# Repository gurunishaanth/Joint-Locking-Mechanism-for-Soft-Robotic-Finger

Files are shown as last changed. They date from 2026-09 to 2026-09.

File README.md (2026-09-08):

# Soft-Robotic-Finger
This is the final backup of my thesis project. <br>
I have some SolidWorks files and some PDFs from the initial process. <br>
Guru Nishaanth Saravanan_MA.pdf is my final Thesis
# Legend
So, <br>
RP means Rack and pinion mechanism. <br>
CM means Compliant mechanism. <br>
LA means linear actuator mechanism. <br>
EM means Electromagnetic mechanism. <br>

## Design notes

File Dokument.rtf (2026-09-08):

Documentation For The Thesis
Week 1(1/9 - 5/9)
Prep for the literature review
Week 2(8/9 - 12/9)
First version of compliant mech
Week 3(15/9 - 19/9)
Thesis write-up and the next version of comp
Documentation
Week 4(22/9 - 26/9)
First version of finger
Documentation
Week 5(29/9 - 3/10)
First version of finger mold
Second version of finger and mold
Documentation
Week 6(6/10 - 10/10)
next version of finger and mold
Documentation
Week 7 (13/10 - 17/10)
First version of Hand design
Documentation
Week 8 (20/10 - 25/10)
Redesign of the finger tip(finger nail)
List of the actuators
Documentation
Week 9 (27/10 - 31/10)
initial mold arrived
Redesign of the whole finger(high width)
design the flex test
Documentation
Week 10(3/11 - 7/11)
design the new mechanism with a rack and pinion
Search for materials
measuring the linear actuator
design the new mechanism with a linear actuator
Documentation
Week 11 (10/11 - 14/11)
Redesign finger
Redesign the RP mechanism and LA mechanism
Documentation
Week 12 (17/11 - 21/11)
Initial print for the comp mech and TPU finger acquired after the 3d print
Documentation
initial re-design drawing and list prep for the re-design
Week 13 (23/11 - 28/11)
Redesign of LA
Redesign of RP
Redesign of finger and molds
Finger design with single string
Week 14(1/12 - 5/12)
Electromagnet 4 parts and lid done
Motor lock structure
test joint v3 and v4 and molds
First test joint done here
Week 15 (8/12 - 12/12)
fabrication part
second attempt on the same test joint
redesign some parts
palm v2
Week 16 (15/12 - 19/12)
Break
Week 17 (22/9 - 26/9)
Break
Week 18 (29/12 - 2/1)
Break
Week 19 (7/1 - 9/1)
Break
Week 20 (12/1 - 16/1)
Break
Week 21 (19/1 - 24/1)
Summary of the project
small re-designs
parameters to choose the actuators acquired
literature review structure
Week 22 (26/1 - 31/1)
Trying to make the electromagnet work
works but very low power, ordered the power supply
Trying to make the linear actuator work
NOT WORKING

Week 23 (2/2 - 7/2)
Trying to make the linear actuator work
NOT WORKING
searching for a new driver.
EM parts redesign
Vachum chamber arrived.
Base test is working.
Did a mold test, added less silicone, so failed.

Week 24 (10/2 - 13/2)
Did a full finger Mold test - WITH VACUME CHAMBER
working but there are bubbles on the top.
EM parts new re-design
nail re-design - (too tight; HARD FOR THE THREAD TO GO IN.)
mold top part redesign

Week 25 (16/2 - 20/2)
full mold design start(discussion)
soft robotic arm redesign
Documentation

Week 26 (22/2 - 27/2)
Single finger BASE
Got the 3d printed parts
Assembled new LA case
new finger got from mold

Week 27 (2/3 - 6/3)
Power source, LA Driver, and Jumper wires arrived
Single-finger base assembled
new finger added the string
EM test code completed
EM basic test - 12V attracts properly

Week 28 (9/3 - 13/3)
LA Test code completed
LA basic test - 6V moves properly, but the 90 Â° movement doesn't work
LA Redesign was done
LA full finger model started

Week 29 (16/3 - 20/3)
LA full finger model the bend thing
LA full finger model molds
EM full finger model the bend thing
EM full finger model molds started
got some 3D printed parts

Week 30 (22/3 - 27/3)
Got 2 souldered LA
broke one Got 1 RP motor
broke Got some 3D printed parts
mini test RP RP redesign
Week 31 (30/3 - 3/4)
EM mold re-design
LA re-design
3D print parts
RP test code

Week 32 (6/4 - 10/4)
got H-bridge, silicon glue, silicone
LA full finger casted

Week 33 (13/4 - 17/4)
worked on LA control
writing
recived 3d prints

Week 34 (20/4 - 24/4)
writing
Control done
Redesign the finger base

Week 35 (27/4 - 1/5)
Literature review writing
Redesign the backbone from plastic to leaf spring
Experimental design writing

Week 36 (4/5 - 8/5)
Experimental design writing
leaf spring initial experiments

Week 37 (18/5 - 22/5)
power experiment set up done
LA finger plastic

Week 38 (25/5 - 29/5)

Week 39 (2/6 - 6/6)

Week 40 (8/6 - 12/6)

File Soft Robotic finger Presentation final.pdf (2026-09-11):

1 | Joint locking mechanisms for Soft Robotic Finger | Guru Nishaanth Saravanan

# Joint Locking Mechanisms for Soft Robotic Finger

# Master’s Thesis

### From Guru Nishaanth Saravanan

1st supervisor: Dr.Julia Starke | 2nd supervisor: Dr. Georg Schildbach

2 | Joint locking mechanisms for Soft Robotic Finger | Guru Nishaanth Saravanan

## Introduction

## Soft Robotics

- High compliance
- Safer robot-human interaction
- Adaptive grasping with fragile and irregular objects.
- Low precision and load capacity

## Hybrid - This Thesis

- Soft Body + locking mechanism
- High compliance
- Safer robot-human interaction
- Adaptive grasping with fragile and irregular objects.
- Higher precision
- Better load capacity

## Rigid Robotics

- High precision and load
capacity
- Poor compliance
- Challenge in interaction with fragile objects and
unstructured environment

[1]

1
2

[2]

3 | Joint locking mechanisms for Soft Robotic Finger | Guru Nishaanth Saravanan

## Introduction

## Need for Locking mechanisms

- Underactuated robotic had uses locking mechanisms to compensate the lack of
actuators.
- These mechanisms locks the fingers on certain positions to have more dexterity by having multiple configurations

## Underactuated Robotics

Drive multiple joints from a single actuator through passive tendon or linkage coupling.

1
2

[1]

4 | Joint locking mechanisms for Soft Robotic Finger | Guru Nishaanth Saravanan

## Literature Review

UT Hand 1 | Mag-Net finger
- This hand is a rigid, underactuated hand that uses a motor to control each finger’s flexion.
- It has an embedded solenoid-based pin-locking mechanism and is used to stop the joint rotation; therefore, locking the joint is in a single position.
- This soft finger is cast using the silicone casting method and is capable of performing flexion motion.
- It has embedded
electromagnetic coils

The gap
Locking strategies exist for rigid systems, but the integration of an embedded rigid locking element into a soft system is non-existent.

[1]

[1]

[3]

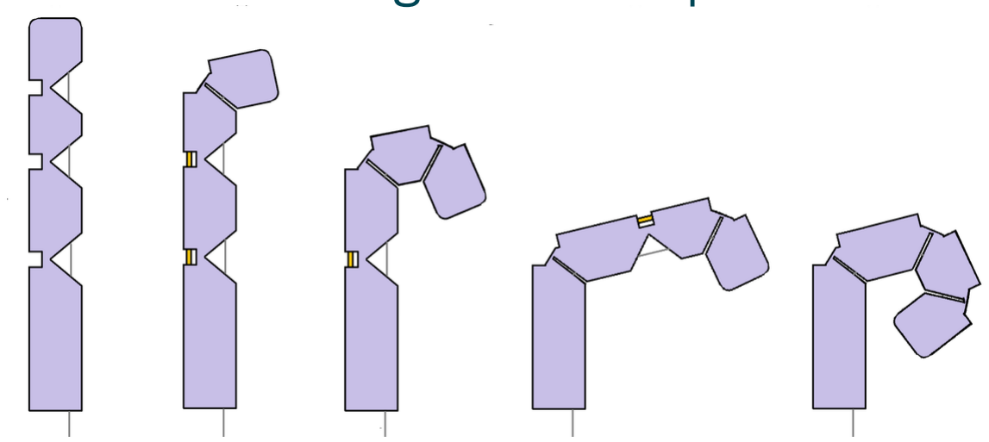
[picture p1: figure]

5 | Joint locking mechanisms for Soft Robotic Finger | Guru Nishaanth Saravanan

## Motivation and Research Gap

The main motivation of the thesis is to make a soft robotic finger that can achieve multiple configurations

How? | Thesis objective
| • Propose and compare multiple candidate mechanisms. • Select and integrate the locking mechanisms into a silicon-cast, tendon-driven finger. • Experiment and validate at mechanism- and finger-level

By implementing, a discrete, electrically controlled locking mechanism, embedded in a soft finger to hold multiple grasp configurations without sacrificing softness or adding excessive power draw.

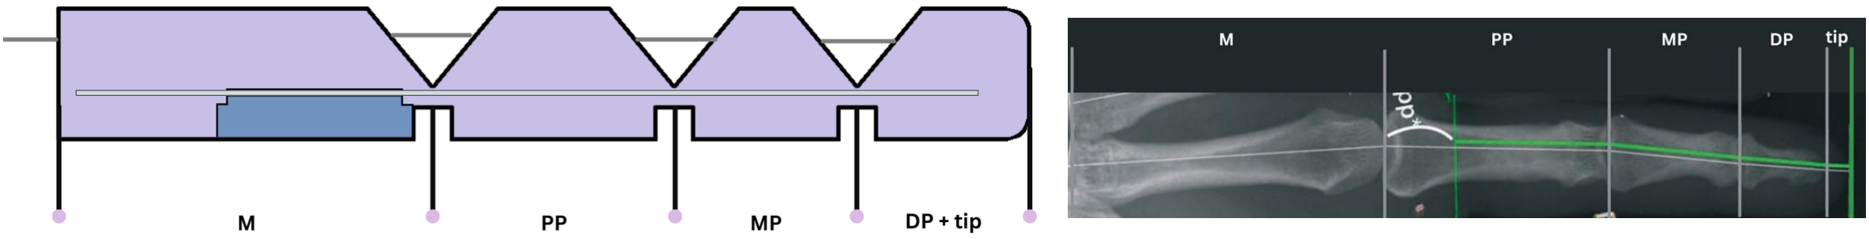
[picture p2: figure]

6 | Joint locking mechanisms for Soft Robotic Finger | Guru Nishaanth Saravanan

## Finger Design

90°
Angle of the finger joint

≥250°
Total Range of motion

(Key requirements)

Segment lengths are constrained to within the anatomically derived targets, keeping proportions consistent with the human middle finger.

Joint 1 | Joint 2 | Joint 3

[4]

## Locking mechanism selection

7 | Joint locking mechanisms for Soft Robotic Finger | Guru Nishaanth Saravanan
Screw based linear mechanism | Rack and pinion mechanism | Compliant mechanism
Electromagnetic mechanism | Pulley system

## Locking mechanism selection

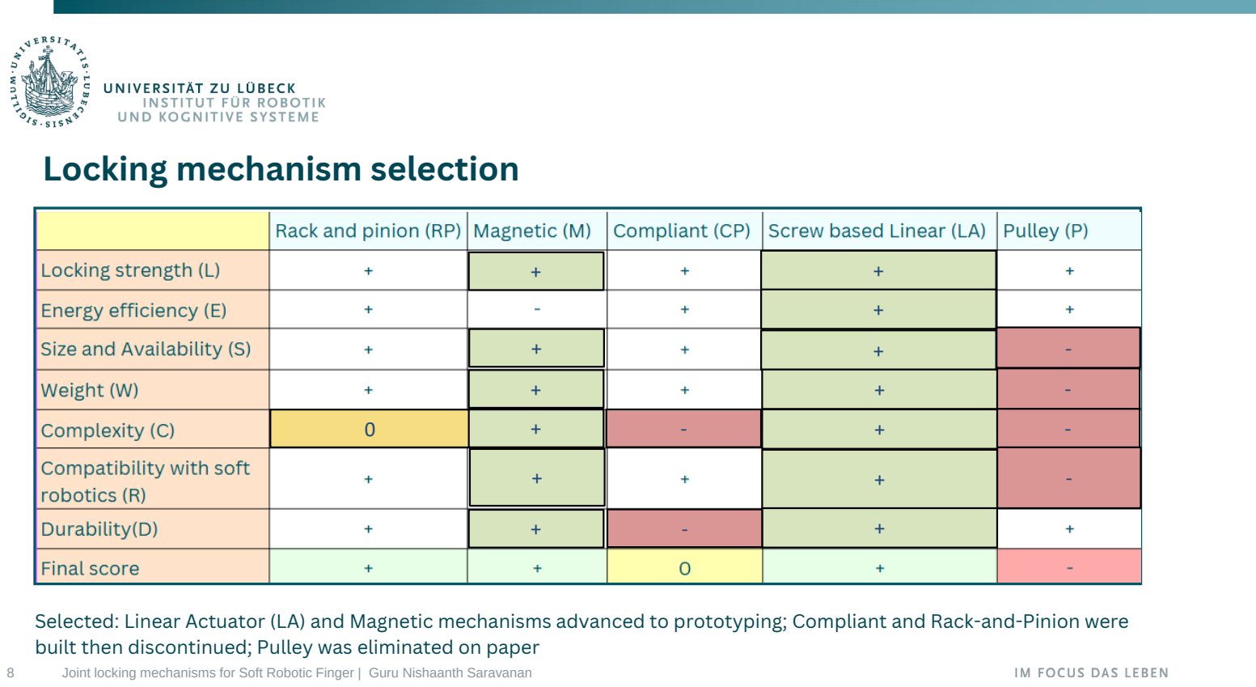
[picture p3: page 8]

8 | Joint locking mechanisms for Soft Robotic Finger | Guru Nishaanth Saravanan

Selected: Linear Actuator (LA) and Magnetic mechanisms advanced to prototyping; Compliant and Rack-and-Pinion were built then discontinued; Pulley was eliminated on paper

0 | + | - | + | -
| + | | + | -

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
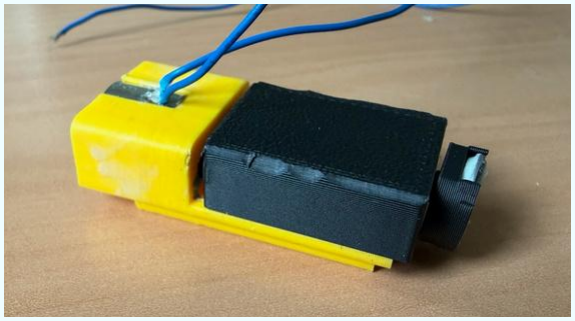
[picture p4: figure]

9 | Joint locking mechanisms for Soft Robotic Finger | Guru Nishaanth Saravanan

## Mechanism designs

Electromagnet Mechanism | Linear actuator Mechanism
- This mechanism relies on an electromagnet and the metal piece for locking. • An electromagnet rated at 24 V, 1.0W, is used for this purpose. | • CA-1006 micro stepper motor - 9 mm stroke is used for this mechanism • Screw-based threaded shaft drives non- backdrivable linear lock.

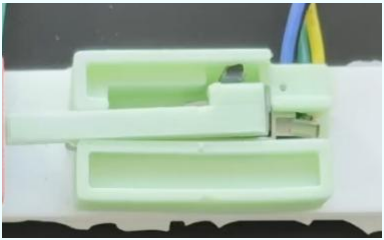
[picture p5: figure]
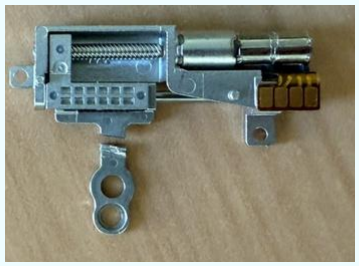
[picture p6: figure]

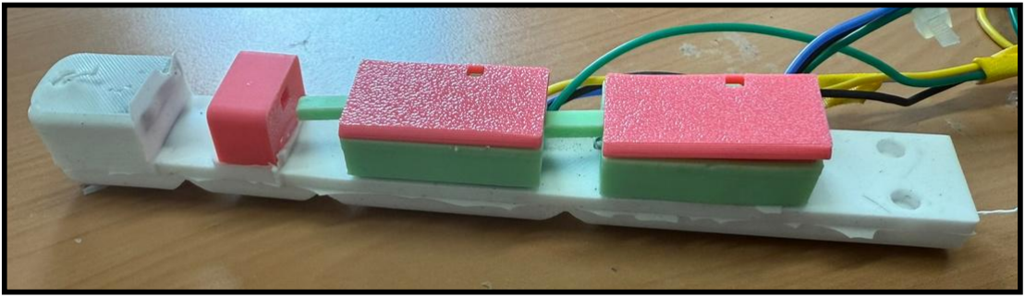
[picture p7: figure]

10 | Joint locking mechanisms for Soft Robotic Finger | Guru Nishaanth Saravanan

## Final fingers

- Two of these final fingers are tested to find the best mechanism, and the best candidate can be used for further construction.
- Locking currently implemented at Joints 1 and 2
- Tendon-driven actuation with PTFE-lined channels
- Anatomically-proportioned segments (166 mm total length)

With the electromagnet mechanisms

With the linear actuator mechanisms

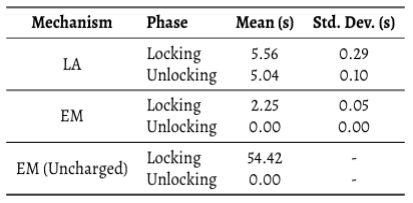
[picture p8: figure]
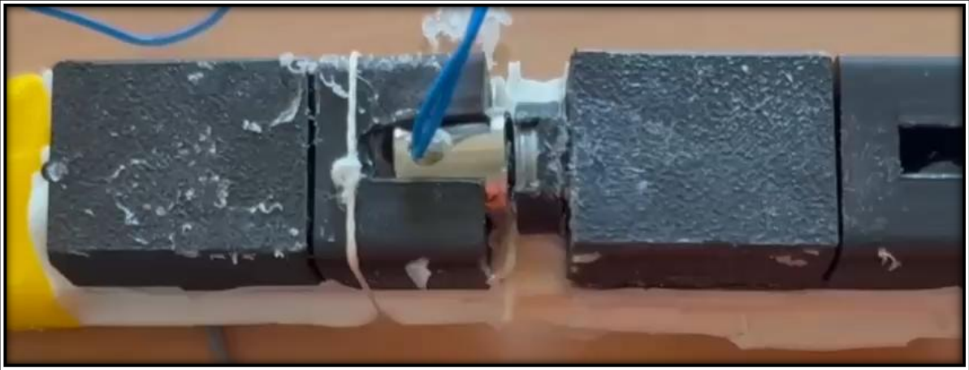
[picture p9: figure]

11 | Joint locking mechanisms for Soft Robotic Finger | Guru Nishaanth Saravanan

## Activation time

## 2.5 s

Electromagnet

## 5.5 s

Linear actuator

Avg Locking time

## Mechanism-Level Experiments

## Power consumption

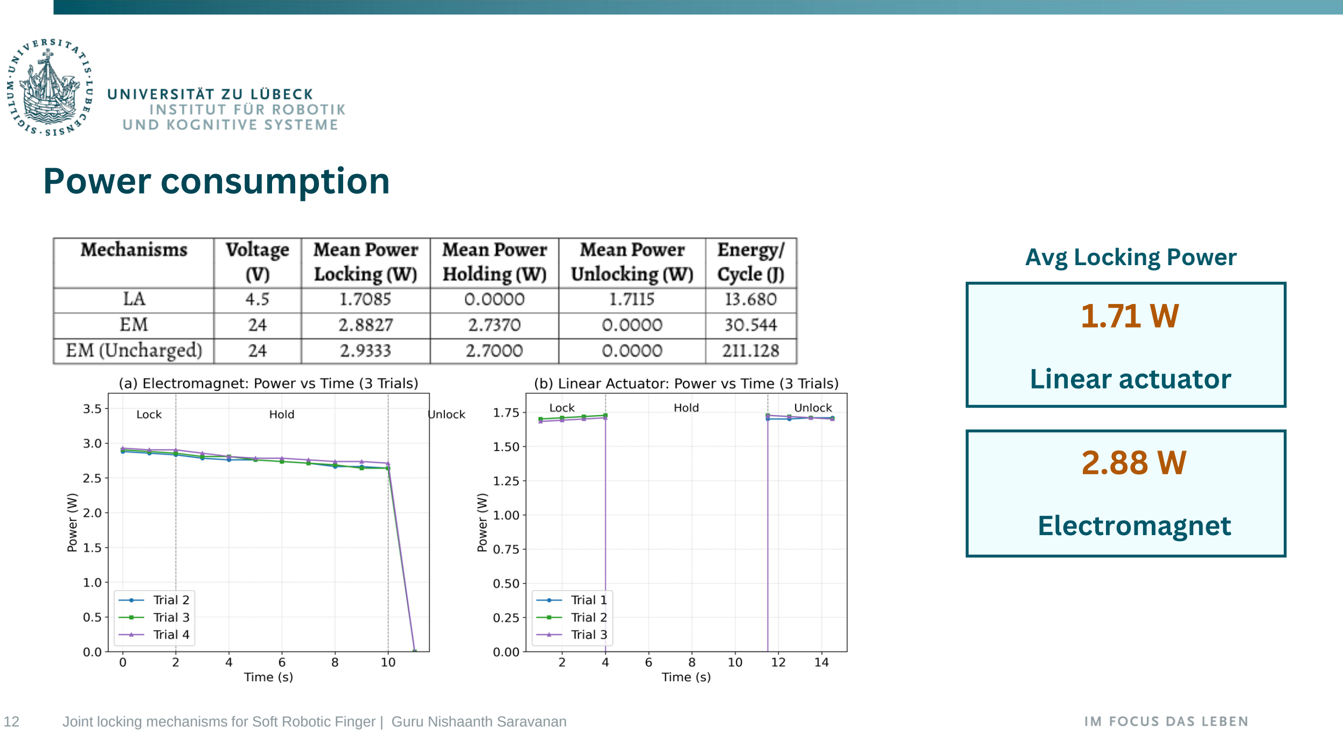
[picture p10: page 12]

12 | Joint locking mechanisms for Soft Robotic Finger | Guru Nishaanth Saravanan

## 2.88 W

Electromagnet

## 1.71 W

Linear actuator

Avg Locking Power

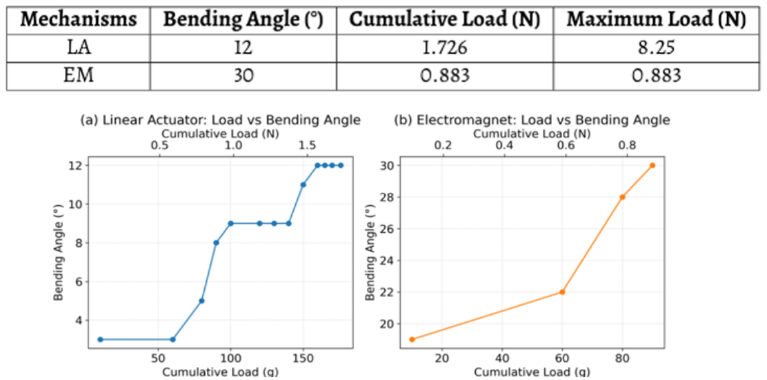
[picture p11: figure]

13 | Joint locking mechanisms for Soft Robotic Finger | Guru Nishaanth Saravanan

## Load carried

## 0.88 N

Electromagnet

## 8.25 N

Linear actuator

Maximum Load

14 | Joint locking mechanisms for Soft Robotic Finger | Guru Nishaanth Saravanan

## Mechanisms overview

### Criteria

Avg. locking time Avg. locking power Max. load Applied | 5.5 s 1.74W 8.25 N | 2.5 s 2.88 W 0.88 N | Electromagnet Linear actuator Linear actuator
| | Final Choice | Linear actuator

### Linear actuator

### Electromagnet

### Preferred

15 | Joint locking mechanisms for Soft Robotic Finger | Guru Nishaanth Saravanan
Tendon pull force | Finger tip strength

2.78 ± 0.24N

Total pull force required

4.1 ± 0.5 N

Finger tip grip strength

- To measure the grip strength of the finger, quantified as the force exerted by the fingertip when fully actuated.
- Key indicator of the finger’s ability to grasp and hold objects during practical use.
- To determine the force required to pull the tendon of the finger through its full range of motion.
- This force is used to calculate the torque required for the actuating motor.

## Finger-Level Experiments

## Precision and repeatability

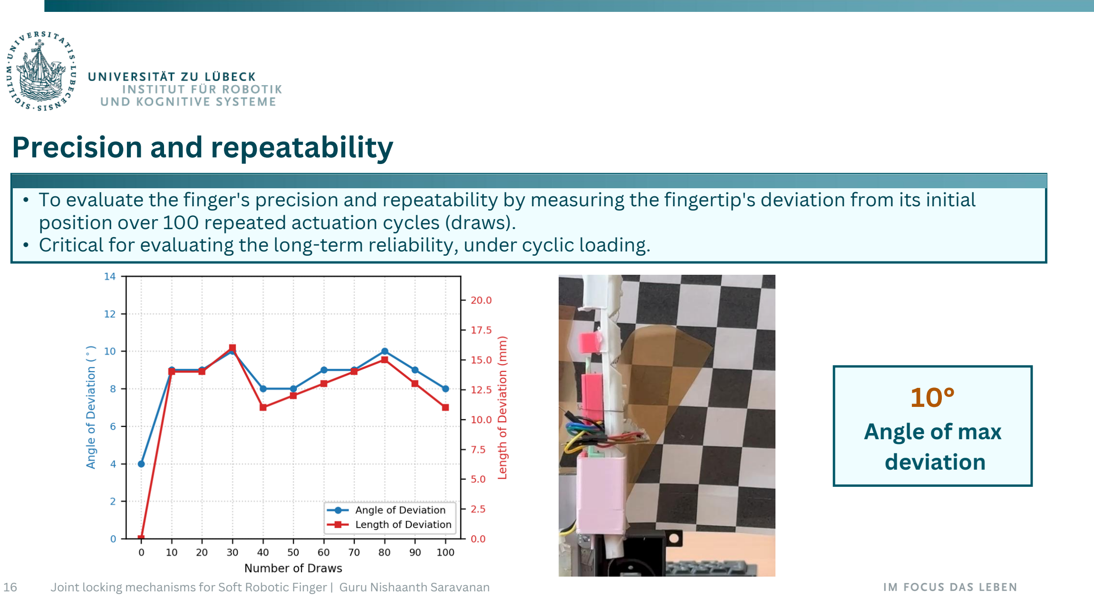
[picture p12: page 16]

16 Joint locking mechanisms for Soft Robotic Finger | Guru Nishaanth Saravanan
- To evaluate the finger's precision and repeatability by measuring the fingertip's deviation from its initial position over 100 repeated actuation cycles (draws).
- Critical for evaluating the long-term reliability, under cyclic loading.

10°
Angle of max
deviation

## Range of motion

17 | Joint locking mechanisms for Soft Robotic Finger | Guru Nishaanth Saravanan
Joint 1 Locked | Joint 2 Locked | Joint 1 and 2 Locked | No Joint Locked

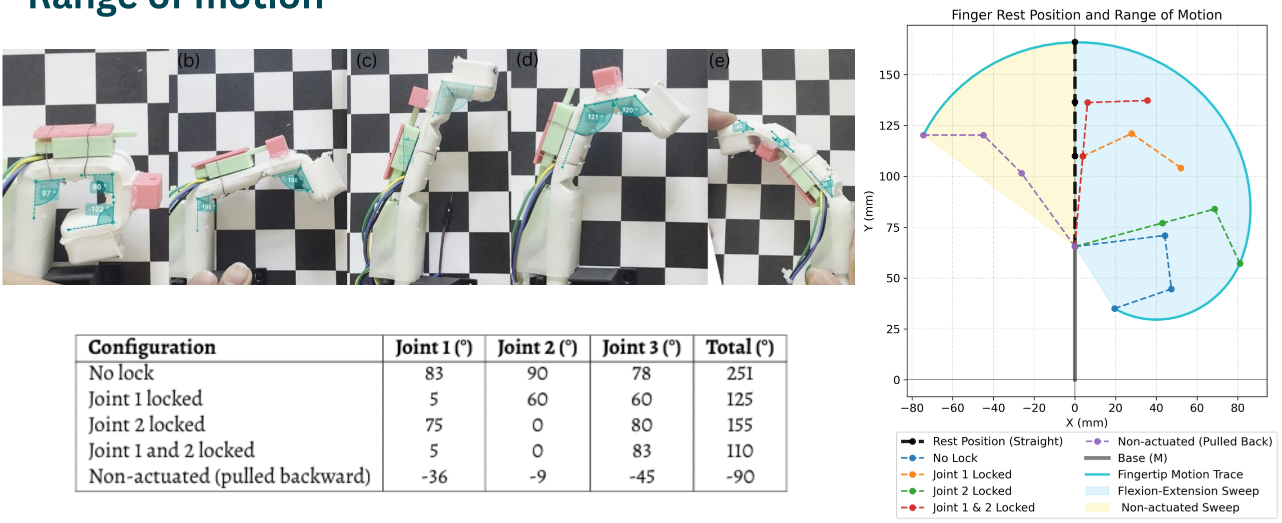
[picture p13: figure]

18 | Joint locking mechanisms for Soft Robotic Finger | Guru Nishaanth Saravanan

## Range of motion

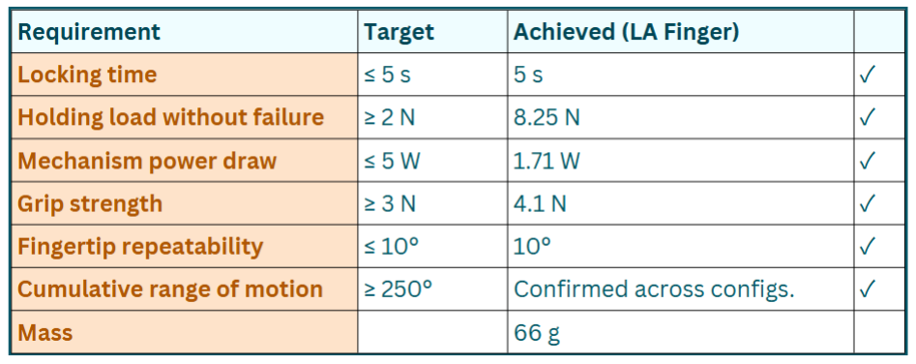
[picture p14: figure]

19 | Joint locking mechanisms for Soft Robotic Finger | Guru Nishaanth Saravanan

## Overview

The target values are taken from the chapter 3 of the thesis.

20 | Joint locking mechanisms for Soft Robotic Finger | Guru Nishaanth Saravanan

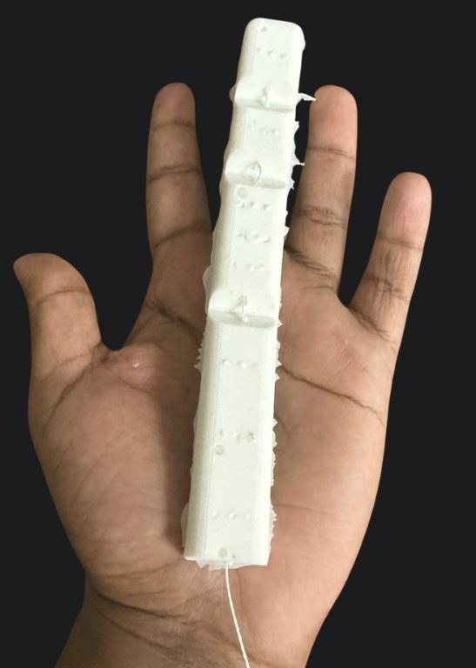
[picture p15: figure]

- Soft finger with an embedded locking mechanism was designed, fabricated, and validated.
- Candidate mechanisms were compared then the linear actuator and electromagnet were carried through to the final designs.
- These two mechanisms were put through an experimental analysis, where the linear actuator was chosen as the final candidate mechanism.
- Experimental results confirm posture retention under load without compromising its inherent soft properties.

## Conclusion

21 | Joint locking mechanisms for Soft Robotic Finger | Guru Nishaanth Saravanan

## Future works

### Motor actuation

Use measured tendon-pull-force data to calculate the required motor torque for optimal actuator selection.

### Full Hand

Scale from a single finger to five fingers integrated into a complete soft robotic hand.

22 | Joint locking mechanisms for Soft Robotic Finger | Guru Nishaanth Saravanan

# Thank you for your attention

Any
questions?

22 | Joint locking mechanisms for Soft Robotic Finger | Guru Nishaanth Saravanan

# References

1. Peerdeman,B et al., UT hand I:A lock-based underactuated hand prosthesis. In: Mechanism and Machine Theory.
2. Pagoli,A et al., A Soft Robotic Gripper With an Active Palm and Reconfigurable Fingers for Fully Dexterous In-Hand Manipulation. In: IEEE Robotics and Automation Letters.
3. Bolanakis,G.and Papadopoulos,E. Introducing Mag-Nets: Rapidly Bending Electromagnetic Actuators for Self-Contained Soft Robots. In: IEEE Robotics and Automation Letters.
4. Buryanov,A and Kotiuk,V. Proportions of Hand Segments. In: International Journal of Morphology.

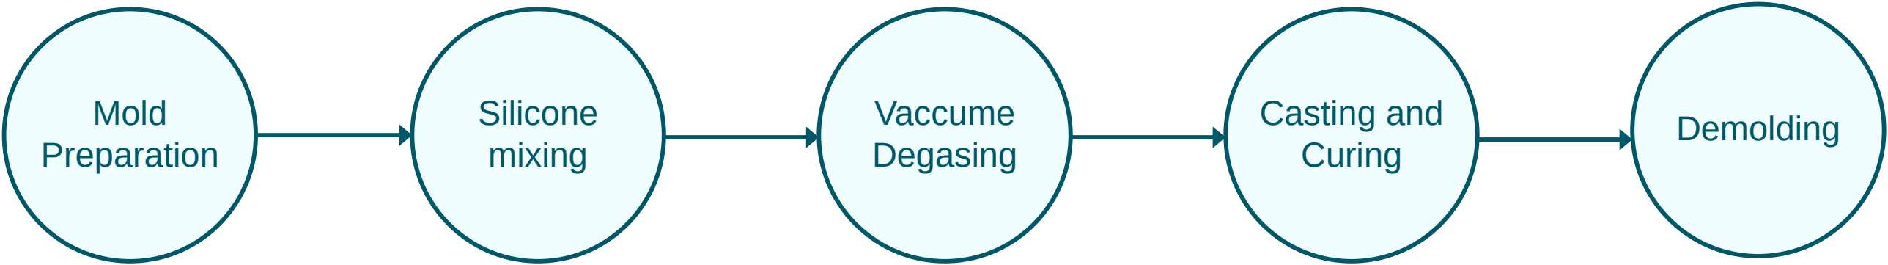
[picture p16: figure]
Mold Preparation; Silicone mixing; Vaccume Degasing; Casting and Curing; Demolding

24 | Joint locking mechanisms for Soft Robotic Finger | Guru Nishaanth Saravanan

## Finger fabrication

25 | Joint locking mechanisms for Soft Robotic Finger | Guru Nishaanth Saravanan

## Compliant mechanism

## Rack and pinion mechanism

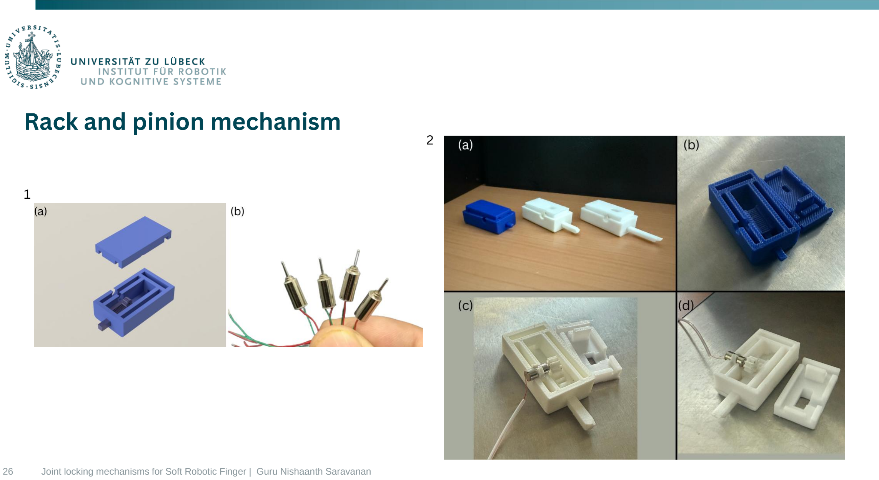
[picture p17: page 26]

26 | Joint locking mechanisms for Soft Robotic Finger | Guru Nishaanth Saravanan

1

2

## Electromagnet mechanism

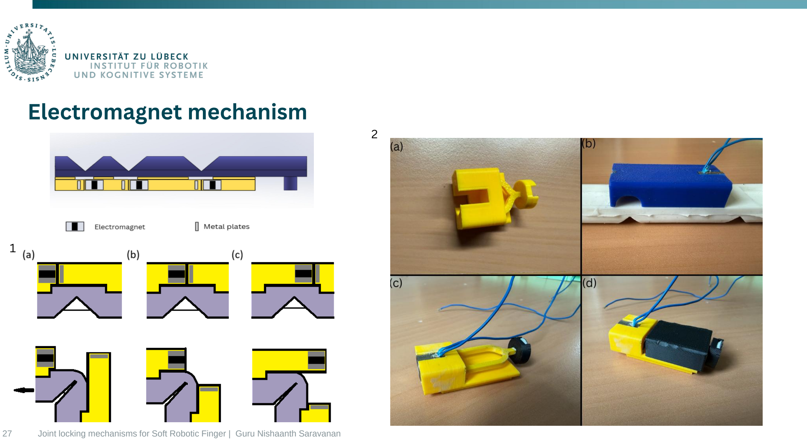
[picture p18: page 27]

27 | Joint locking mechanisms for Soft Robotic Finger | Guru Nishaanth Saravanan

1

2

## Linear actuator mechanism

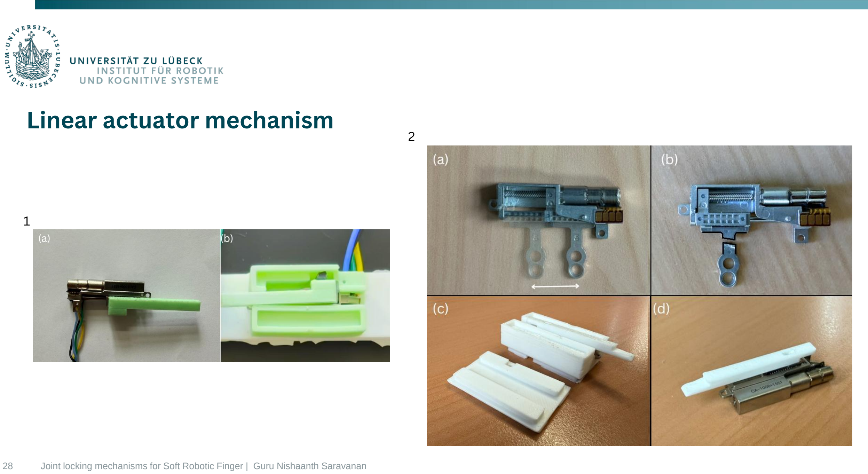
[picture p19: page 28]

28 | Joint locking mechanisms for Soft Robotic Finger | Guru Nishaanth Saravanan

2

1

29 | Joint locking mechanisms for Soft Robotic Finger | Guru Nishaanth Saravanan

## Spring Steel and PLA backbone

Flexion motion | Modular finger

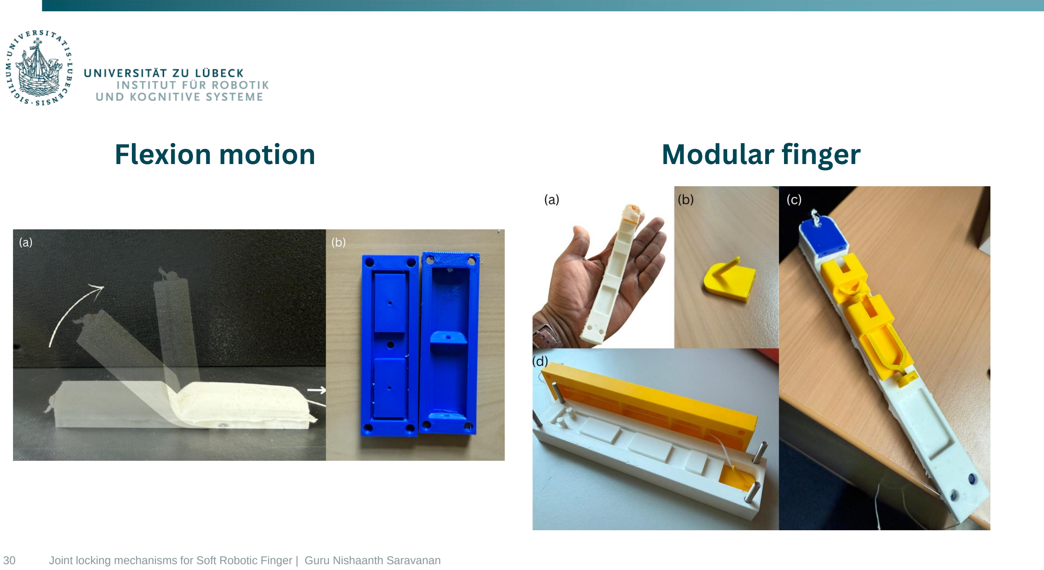
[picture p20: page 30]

30 | Joint locking mechanisms for Soft Robotic Finger | Guru Nishaanth Saravanan

LA finger | EM finger

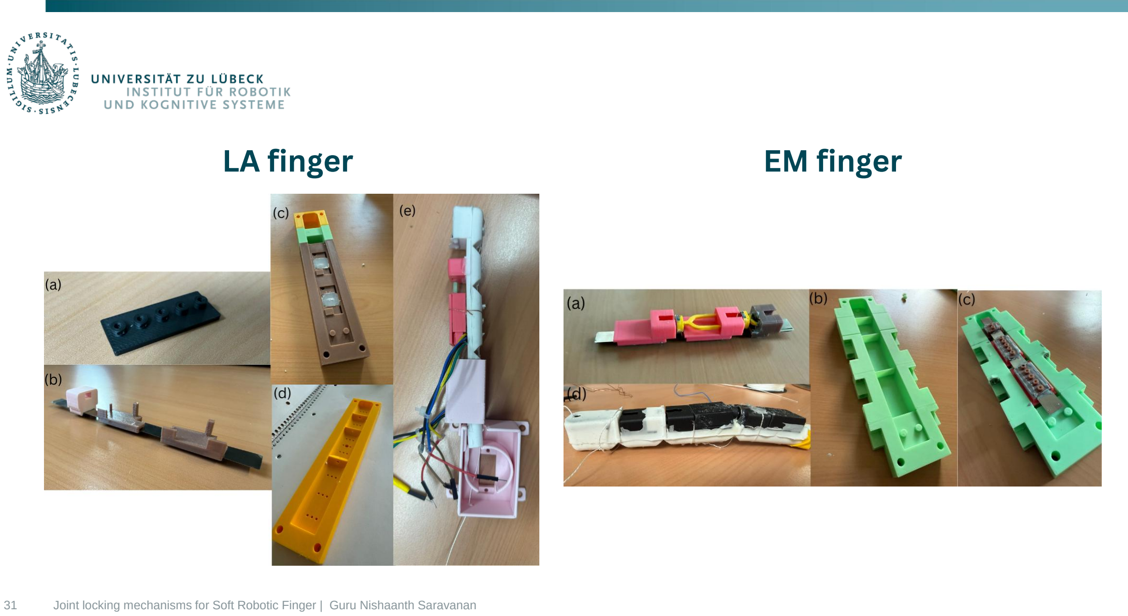
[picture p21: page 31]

31 | Joint locking mechanisms for Soft Robotic Finger | Guru Nishaanth Saravanan

## Experiments

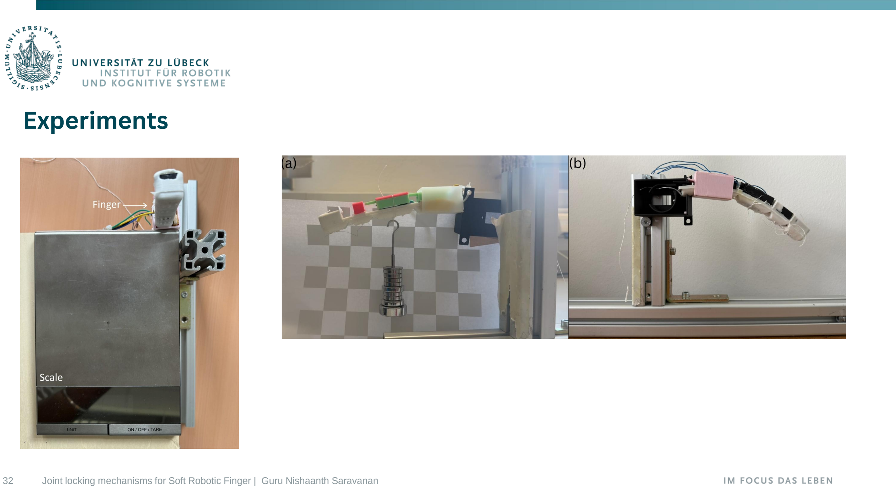
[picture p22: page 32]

32 | Joint locking mechanisms for Soft Robotic Finger | Guru Nishaanth Saravanan

## Control

33 | Joint locking mechanisms for Soft Robotic Finger | Guru Nishaanth Saravanan

## Versions

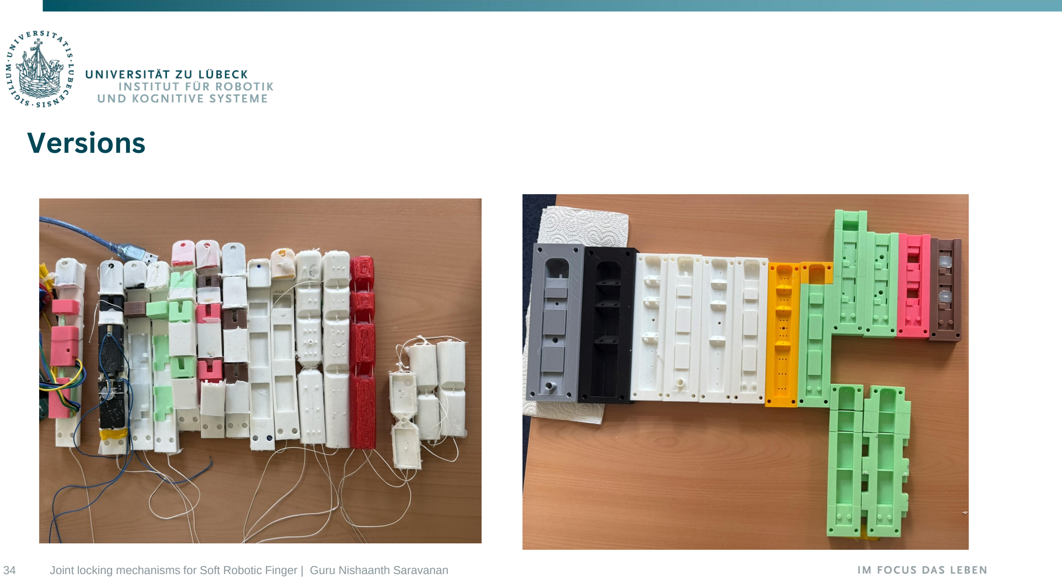
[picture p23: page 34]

34 | Joint locking mechanisms for Soft Robotic Finger | Guru Nishaanth Saravanan

35 | Joint locking mechanisms for Soft Robotic Finger | Guru Nishaanth Saravanan

## Driving Actuator vs the locking actuator

- Smaller
- less power consuming
- Needs less torque

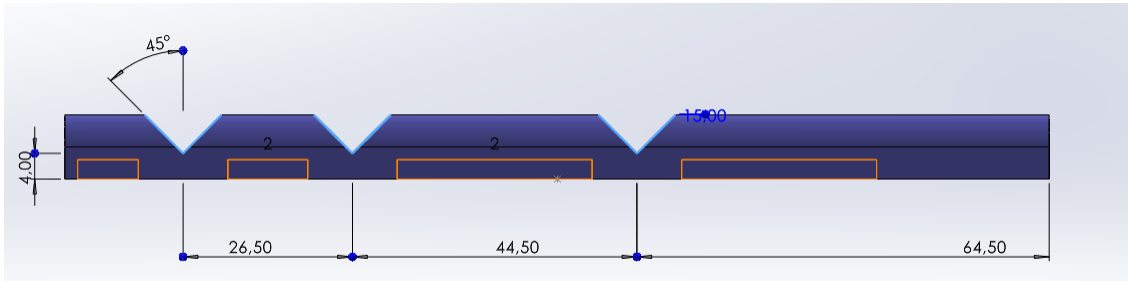
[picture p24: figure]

36 | Joint locking mechanisms for Soft Robotic Finger | Guru Nishaanth Saravanan

## Anatomy

- 1 : 1.5 : 2.6: 3.7 for the segments DP:MP:PP:M.
- Tip = 3.95 ± 0.61mm, DP=17.40±1.85mm, MP=26.33±3.00mm, PP=44.63±3.81mm, and M= 64.60±5.38mm
- Finger length – 166mm

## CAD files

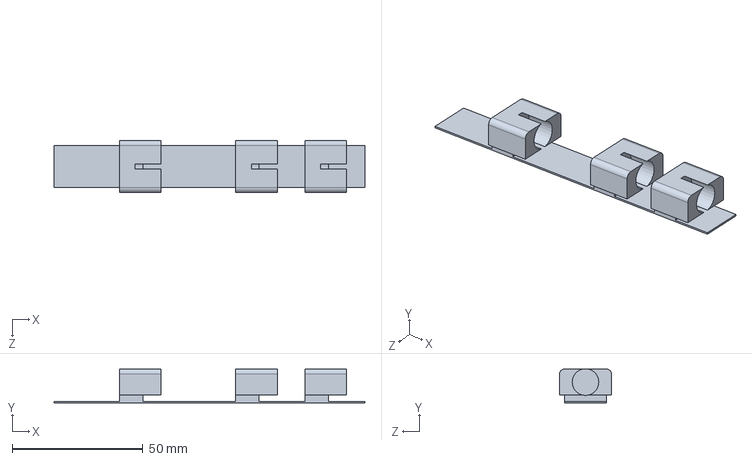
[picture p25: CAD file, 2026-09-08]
Full Finger EM/EM for full finger flex.SLDPRT
119.0 x 13.0 x 20.0 mm

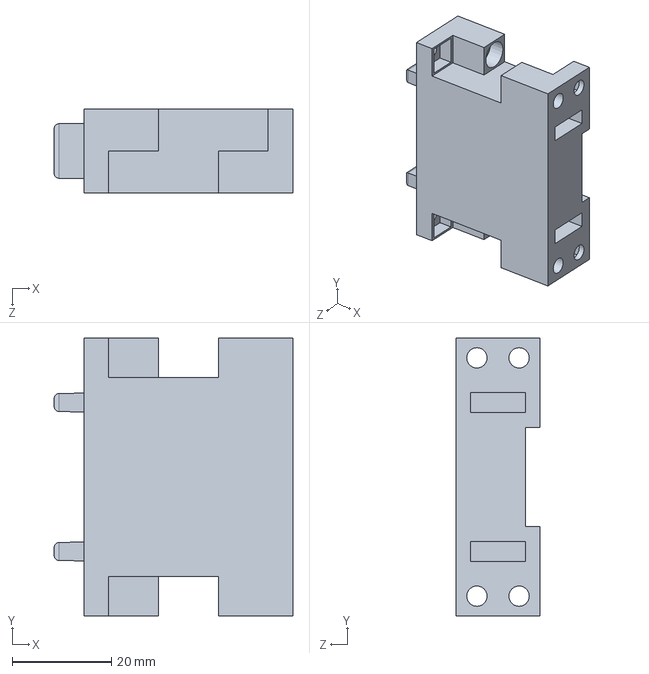
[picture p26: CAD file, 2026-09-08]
Full Finger EM/full finger sample EM mold p4 v3.SLDPRT
48.1 x 56.0 x 17.0 mm

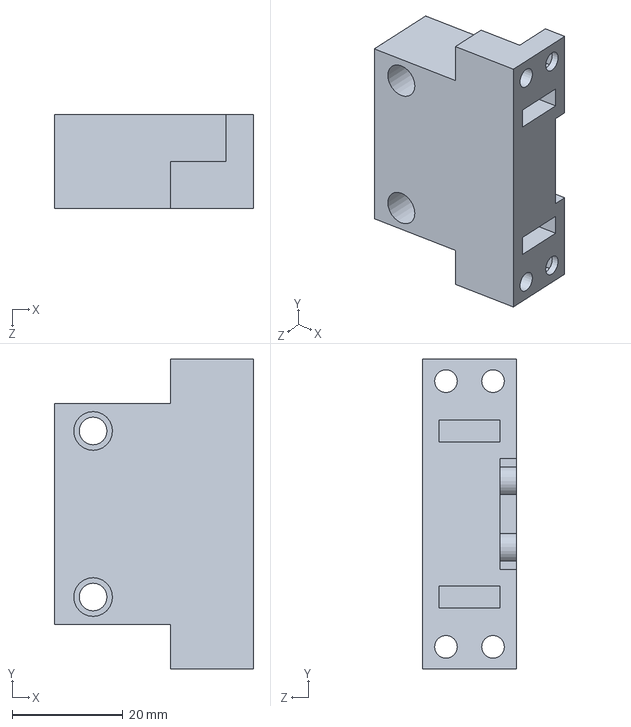
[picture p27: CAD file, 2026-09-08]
Full Finger EM/full finger sample EM mold p5 v3.SLDPRT
36.0 x 56.0 x 17.0 mm

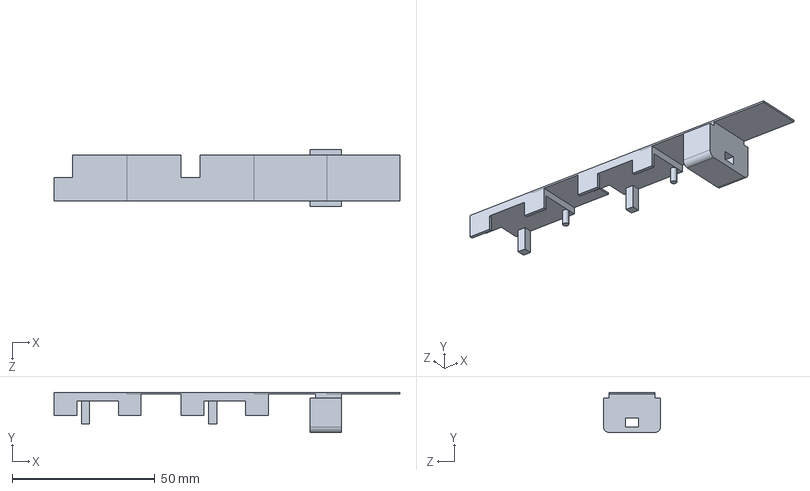
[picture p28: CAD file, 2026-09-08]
Full finger LA/full finger LA for mold.SLDPRT
121.0 x 14.0 x 20.0 mm

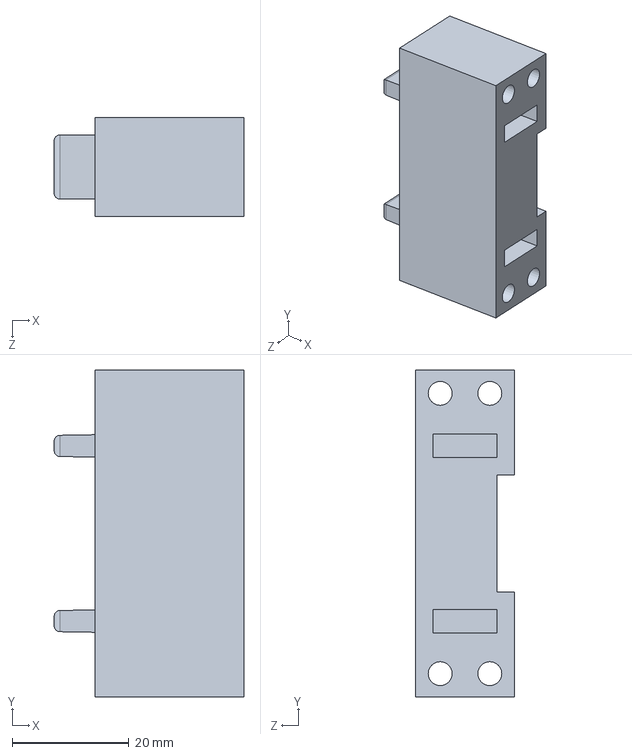
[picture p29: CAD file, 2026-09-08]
Full Finger EM/full finger sample EM mold p2 v3.SLDPRT
32.5 x 56.0 x 17.0 mm

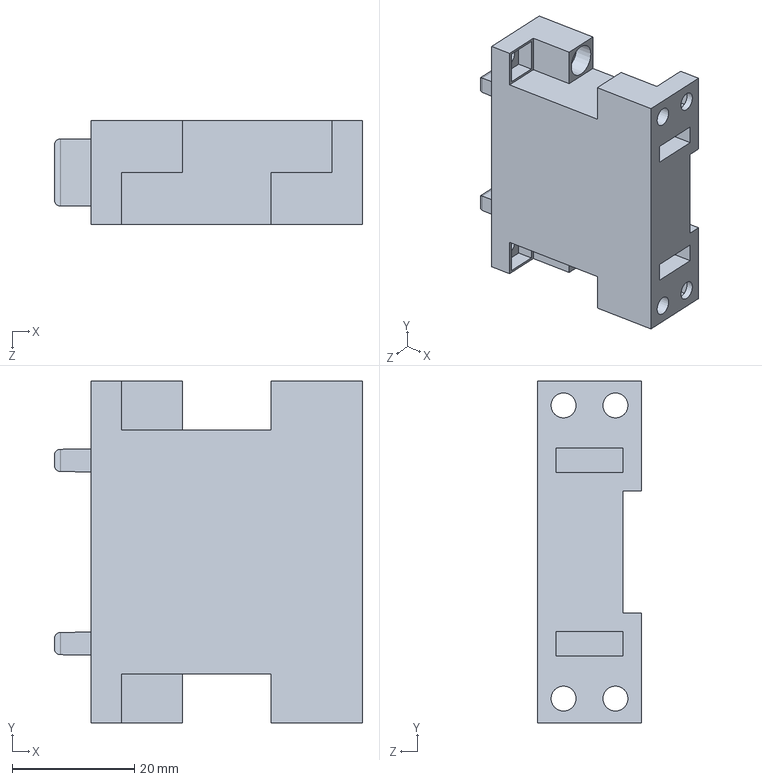
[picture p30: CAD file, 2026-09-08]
Full Finger EM/full finger sample EM mold p3 v3.SLDPRT
50.5 x 56.0 x 17.0 mm

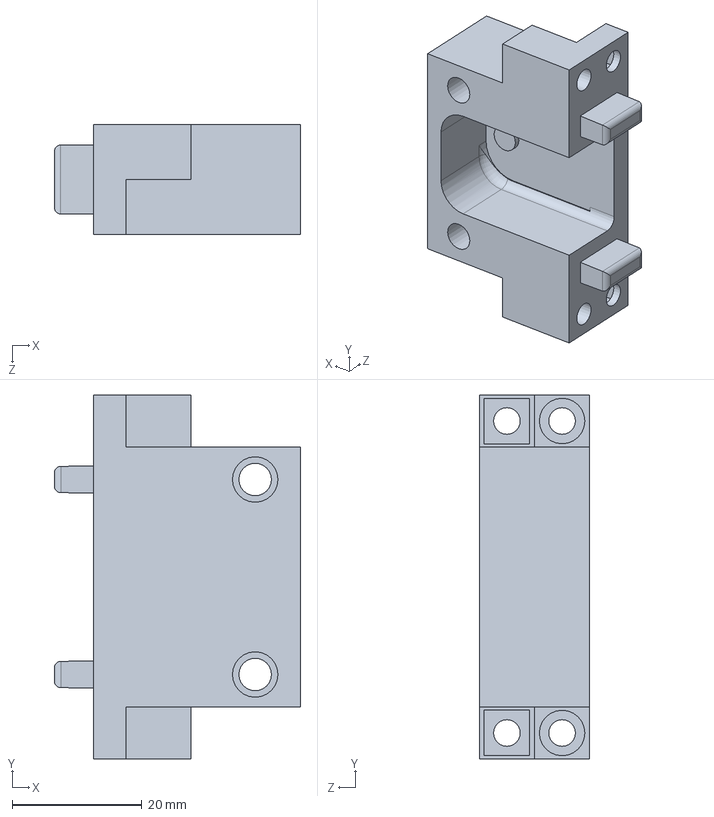
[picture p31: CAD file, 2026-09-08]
Full Finger EM/full finger sample EM mold p1 v3.SLDPRT
37.9 x 56.0 x 17.0 mm

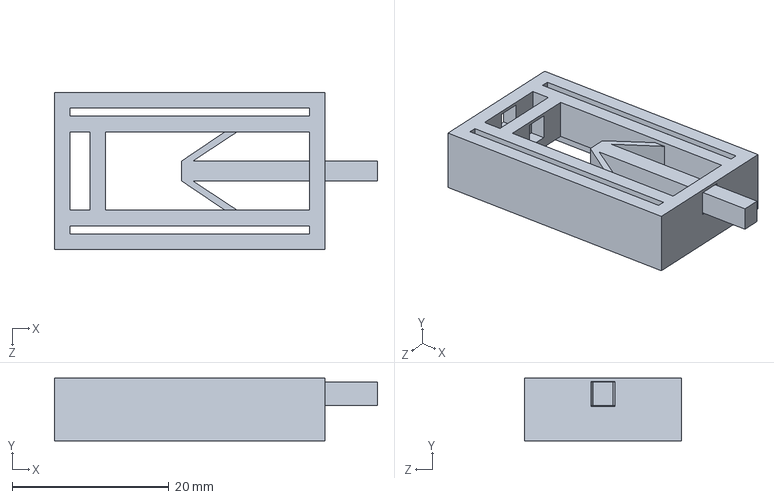
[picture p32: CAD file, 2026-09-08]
CM/compliant mechanism ver5 ph2 v3.SLDPRT
41.2 x 8.00 x 20.0 mm

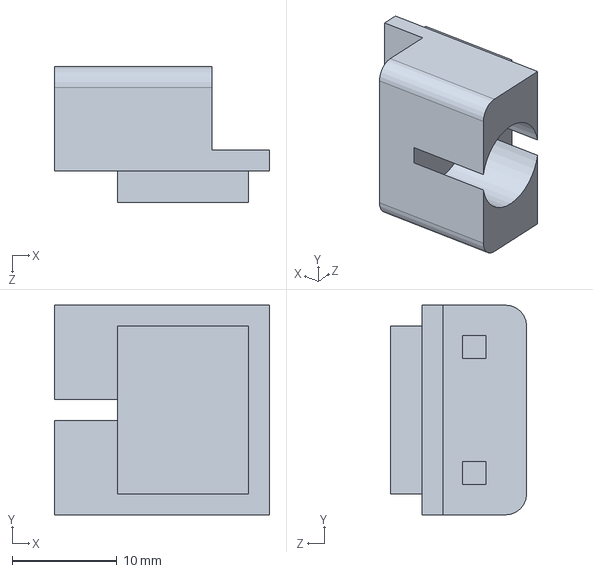
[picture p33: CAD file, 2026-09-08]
EM/Base 3 EM V3.SLDPRT
20.5 x 20.0 x 13.0 mm

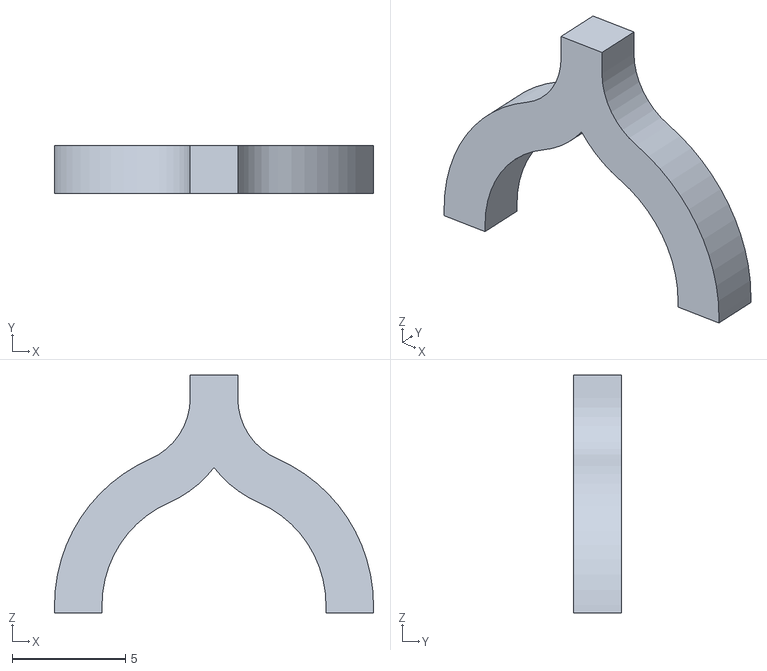
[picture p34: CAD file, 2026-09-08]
EM/STL/Base 3 EM P2 V5.STL
14.1 x 2.10 x 10.5

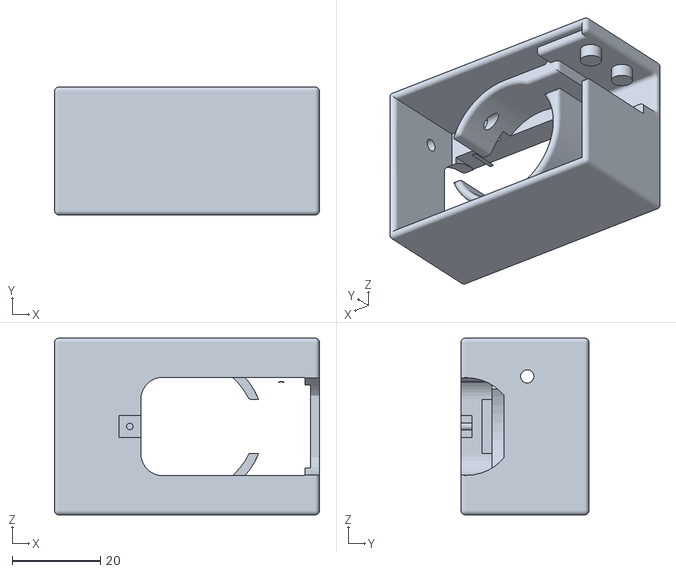
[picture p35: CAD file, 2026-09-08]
finger base/STL/finger base flex v7.STL
60.0 x 29.0 x 40.0

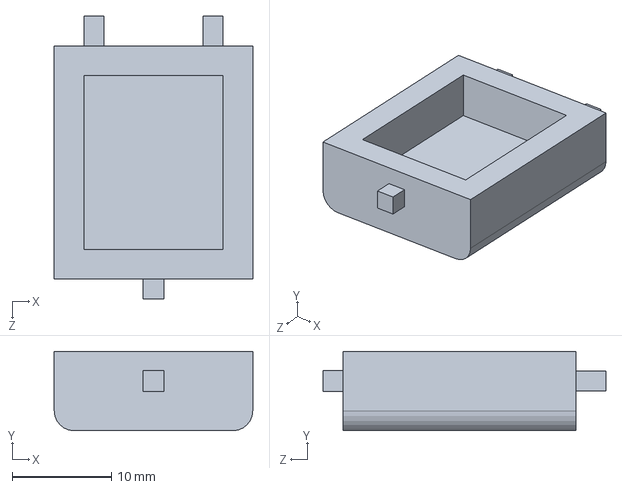
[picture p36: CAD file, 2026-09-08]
Full Finger EM/Base 2 EM P2 V6.SLDPRT
20.0 x 8.00 x 28.5 mm

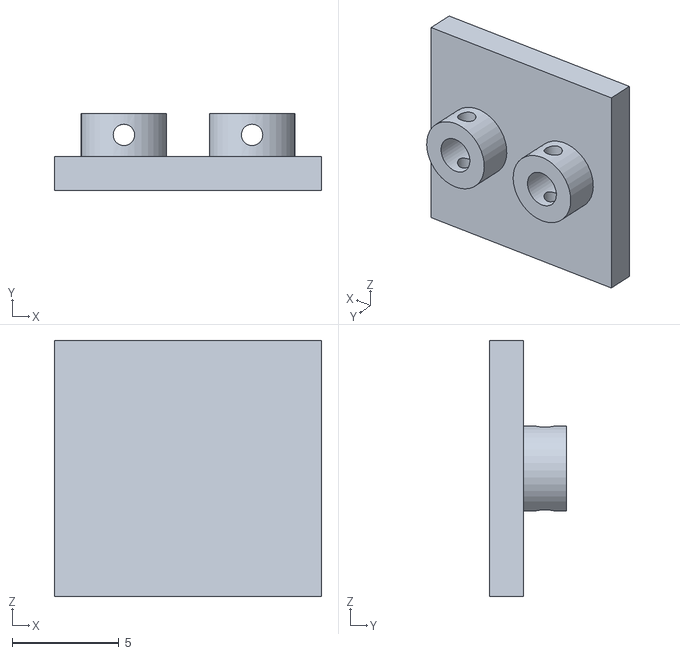
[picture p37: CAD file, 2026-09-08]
Full Finger EM/stl/Base 3 EM V5 P2.STL
12.5 x 3.60 x 12.0

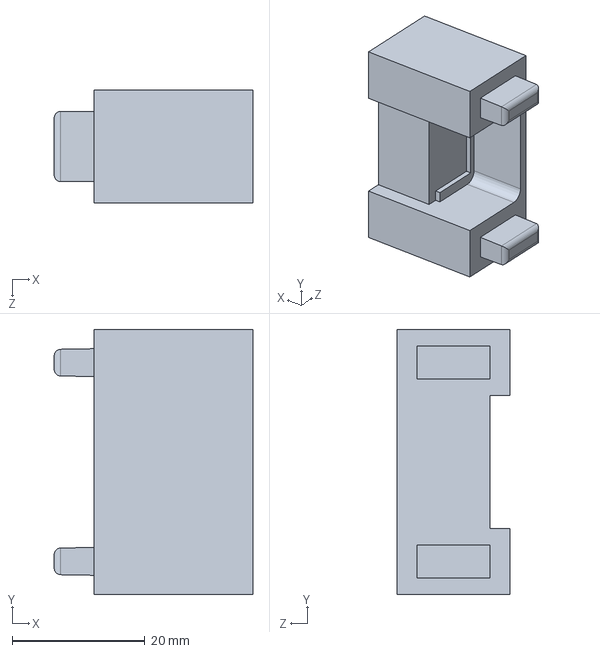
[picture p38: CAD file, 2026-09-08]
Full finger LA/Finger mold LA v8 1 pt1 single mold s3.SLDPRT
30.0 x 40.0 x 17.0 mm

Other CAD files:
finger base/new base.SLDASM
Full Finger/Finger mold v8.2 1 pt1 single mold.SLDPRT
LA/shaft LA V78.SLDPRT
LA/STL/shaft LA V8.STL
CM/STL/compliant mechanism ver5 ph2 v3.STL
EM/Base 2 EM P2 V5.SLDPRT
EM/Base 2 EM V3.SLDPRT
EM/STL/Base 2 EM P2 V5.STL
EM/STL/Base 2 EM V3.STL
EM/STL/Base 3 EM V3.STL
EM/STL/Base 4 EM V4.STL
Full Finger EM/Base 2 EM P1 V5.SLDPRT
Full Finger EM/Base 2 EM V4 P1.SLDPRT
Full Finger EM/Base 2 EM V5 P2.SLDPRT
Full Finger EM/Base 3 EM P2 V5.SLDPRT
Full Finger EM/Base 4 EM V4.SLDPRT
Full Finger EM/stl/Base 2 EM P1 V5.STL
Full Finger EM/stl/Base 2 EM P2 V6.STL
Full Finger EM/stl/Base 2 EM V4 P1.STL
Full Finger EM/stl/Base 2 EM V5 P2.STL
Full Finger EM/stl/Base 3 EM V4 P1.STL
Full Finger EM/stl/Base 4 EM V4.STL
Full Finger EM/stl/EM for full finger flex.STL
Full Finger EM/stl/full finger sample EM mold p1 v3.STL
Full Finger EM/stl/full finger sample EM mold p2 v3.STL
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

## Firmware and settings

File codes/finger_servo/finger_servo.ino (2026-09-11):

#include <Servo.h> 
int servoPin = 12;
Servo Servo1;
void setup() {
  // put your setup code here, to run once:
  Servo1.attach(servoPin); 
}

void loop() {
  // put your main code here, to run repeatedly:
  // Make servo go to 0 degrees 
   Servo1.write(0); 
   delay(1000); 
   // Make servo go to 90 degrees 
  // Servo1.write(180); 
   //delay(1000); 
   // Make servo go to 180 degrees 
   Servo1.write(90); 
   delay(1000); 

}

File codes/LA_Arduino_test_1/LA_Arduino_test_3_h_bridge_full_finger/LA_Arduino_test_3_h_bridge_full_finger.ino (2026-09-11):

int IN1 = 8;
int IN2 = 9;
int IN3 = 10;
int IN4 = 11;
int IN11 = 3;
int IN22 = 4;
int IN33 = 5;
int IN44 = 6;
int INA = 0;
int INB = 0;
int INC = 0;
int IND = 0;
int motor = 1;
int stepIndex = 1;
int direction = 1; // 1 = forward, -1 = backward

int stepsPerRev = 100; // adjust to your motor

void setup() {
  pinMode(IN1, OUTPUT);
  pinMode(IN2, OUTPUT);
  pinMode(IN3, OUTPUT);
  pinMode(IN4, OUTPUT);

  pinMode(IN11, OUTPUT);
  pinMode(IN22, OUTPUT);
  pinMode(IN33, OUTPUT);
  pinMode(IN44, OUTPUT);

  Serial.begin(9600);
}

void stepMotor(int step, int motor) {
  if (motor == 1){
      INA = IN1;
      INB = IN2;
      INC = IN3;
      IND = IN4;
      }
  if (motor == 2){
      INA = IN11;
      INB = IN22;
      INC = IN33;
      IND = IN44;
      }
      
  switch(step) {
    case 0: // A+, B+
      digitalWrite(INA, HIGH);
      digitalWrite(INB, LOW);
      digitalWrite(INC, HIGH);
      digitalWrite(IND, LOW);
      break;

    case 1: // A-, B+
      digitalWrite(INA, LOW);
      digitalWrite(INB, HIGH);
      digitalWrite(INC, HIGH);
      digitalWrite(IND, LOW);
      break;

    case 2: // A-, B-
      digitalWrite(INA, LOW);
      digitalWrite(INB, HIGH);
      digitalWrite(INC, LOW);
      digitalWrite(IND, HIGH);
      break;

    case 3: // A+, B-
      digitalWrite(INA, HIGH);
      digitalWrite(INB, LOW);
      digitalWrite(INC, LOW);
      digitalWrite(IND, HIGH);
      break;
  }
}

void moveSteps(int steps, int motor ) {
  for (int i = 0; i < steps; i++) {
    stepMotor(stepIndex , motor);

    stepIndex += direction;

    if (stepIndex > 3) stepIndex = 0;
    if (stepIndex < 0) stepIndex = 3;

    delay(5); // speed control
  }
}

void loop() {

  if (Serial.available() > 0) {
    int incoming = Serial.read();

    if (incoming == '1') {
      Serial.println("Moving forward - lock - Joint 1");
      direction = 1;
      moveSteps(stepsPerRev * 10 , 1);
    } 
    else if (incoming == '2') {
      Serial.println("Moving backward - unlock - Joint 1");
      direction = -1;
      moveSteps(stepsPerRev * 10 , 1);
    }
    if (incoming == '3') {
      Serial.println("Moving forward - lock - Joint 2");
      direction = 1;
      moveSteps(stepsPerRev * 10 , 2);
    } 
    else if (incoming == '4') {
      Serial.println("Moving backward - unlock - Joint 2");
      direction = -1;
      moveSteps(stepsPerRev * 10 , 2);
    }
  }

}
